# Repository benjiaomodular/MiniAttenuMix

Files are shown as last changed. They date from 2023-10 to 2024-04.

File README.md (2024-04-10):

# MiniAttenuMix

[][cc-by-sa]

A CV mixer with attenuverted inputs.

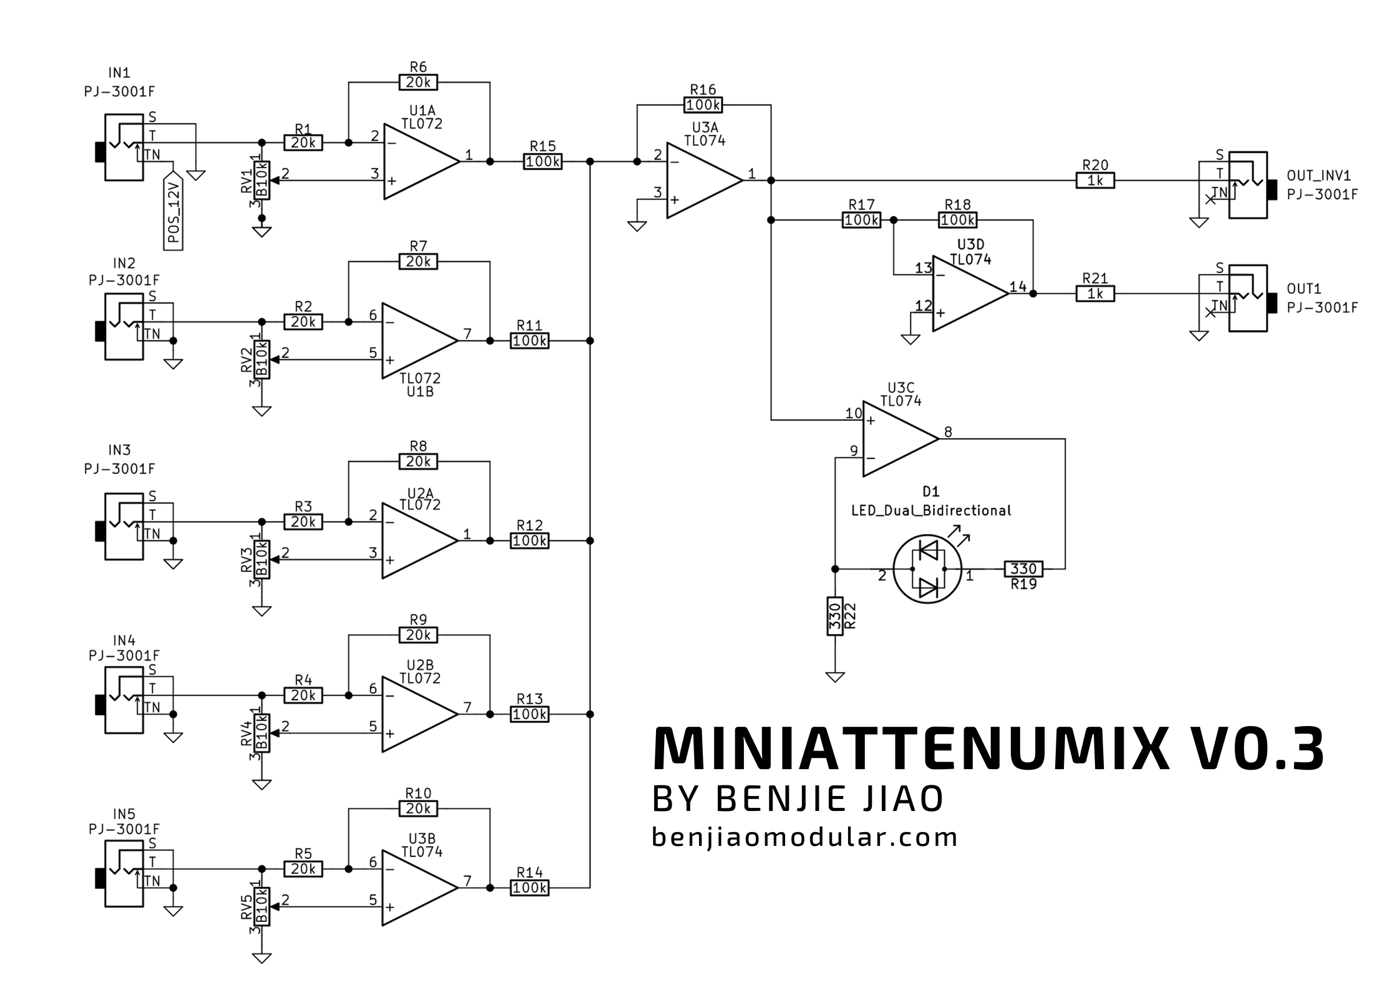
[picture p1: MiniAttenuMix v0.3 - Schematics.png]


# Dependencies
- Made with Kicad v6.
- Install my [KiCAD Libraries](https://github.com/benjiaomodular/KiCadLibraries).

# Changelog

## v0.3 LED Fix 2 (Unverified)
- Moved wiring of LED to the output of first mixing stage (Pin 1 of U3)
- Mistake on OpAmp setup for LED.

## v0.2 LED Fix (Does not work)
- Moved wiring of LED to the output of first mixing stage (Pin 1 of U3)
- Mistake on OpAmp setup for LED.

## v0.1 Initial Release (Does not work)
- LED doesn't function properly

# License

This work is licensed under a
[Creative Commons Attribution-ShareAlike 4.0 International License][cc-by-sa].

[][cc-by-sa]

[cc-by-sa]: http://creativecommons.org/licenses/by-sa/4.0/
[cc-by-sa-image]: https://licensebuttons.net/l/by-sa/4.0/88x31.png
[cc-by-sa-shield]: https://img.shields.io/badge/License-CC%20BY--SA%204.0-lightgrey.svg

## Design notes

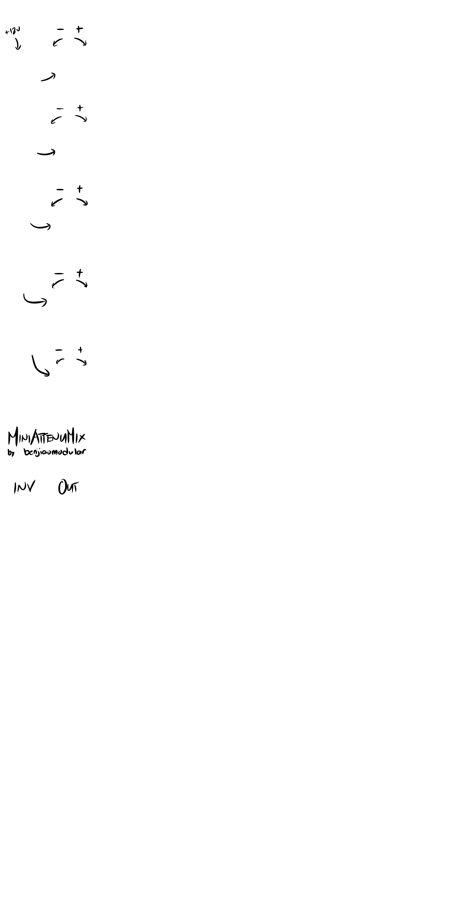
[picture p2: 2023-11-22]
MiniAttenuMix/MiniAttenuMix v0.3/MiniAttenumix - Panel/.svg2shenzhen-cache/images/F.SilkS_g1418.png

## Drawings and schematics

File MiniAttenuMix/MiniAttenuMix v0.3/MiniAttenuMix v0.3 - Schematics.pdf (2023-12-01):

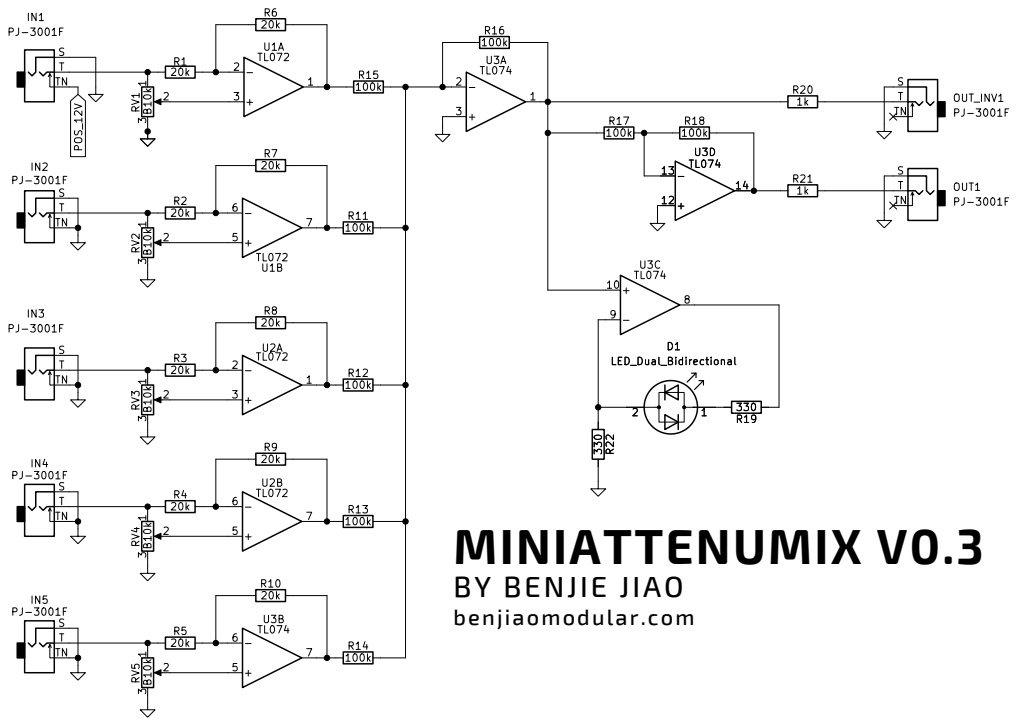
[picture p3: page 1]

MINIATTENUMIX V0.3
BY BENJIE JIAO
benjiaomodular.com

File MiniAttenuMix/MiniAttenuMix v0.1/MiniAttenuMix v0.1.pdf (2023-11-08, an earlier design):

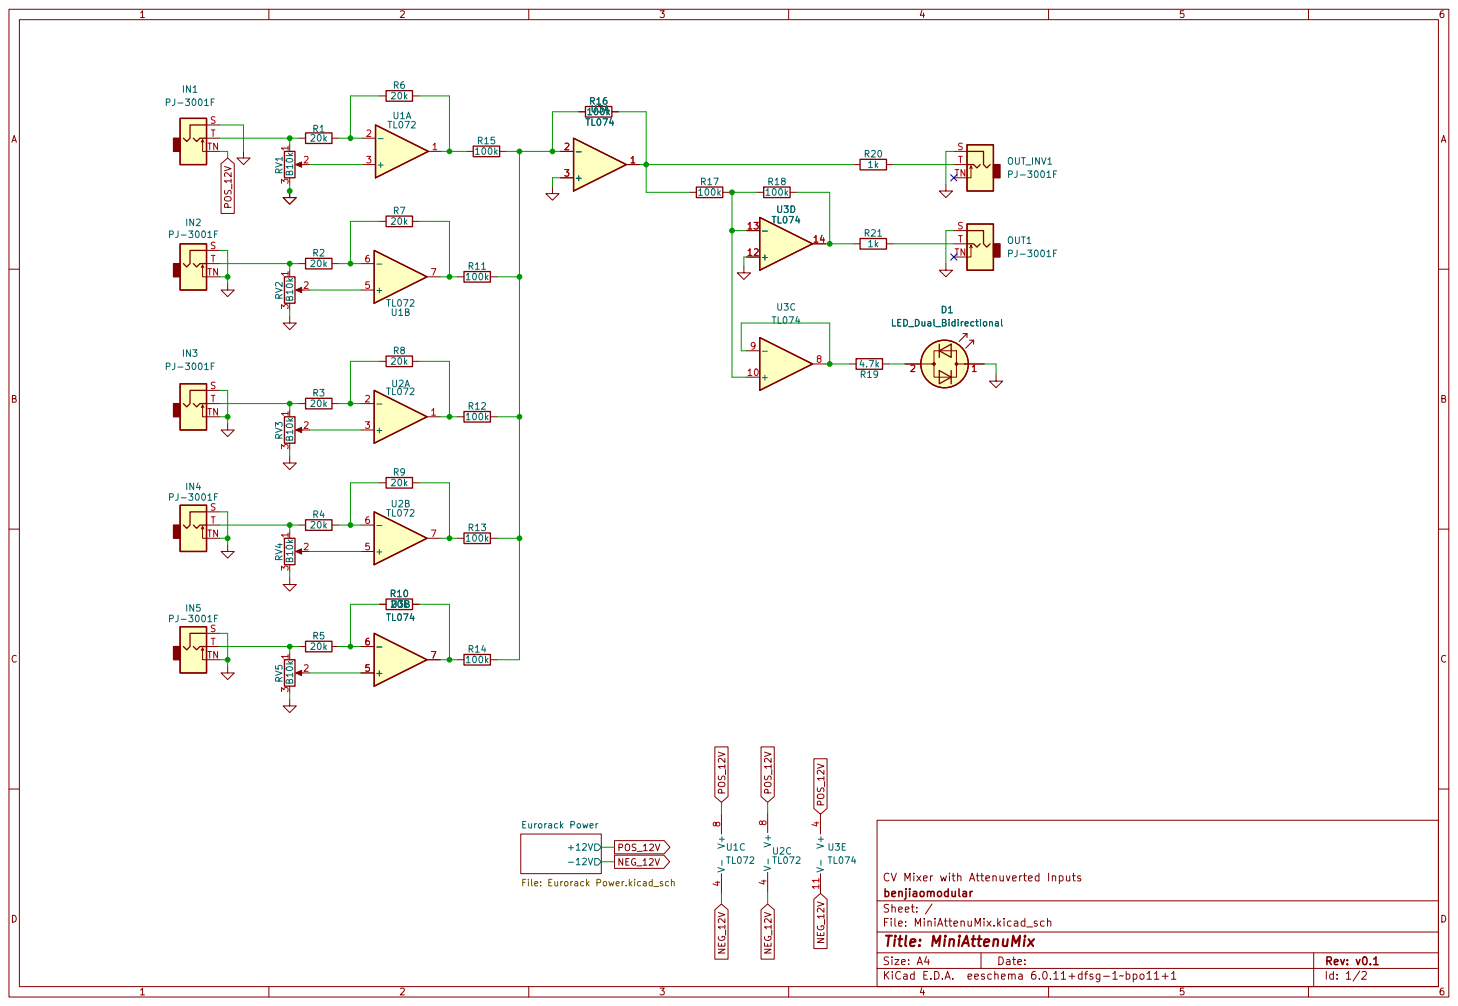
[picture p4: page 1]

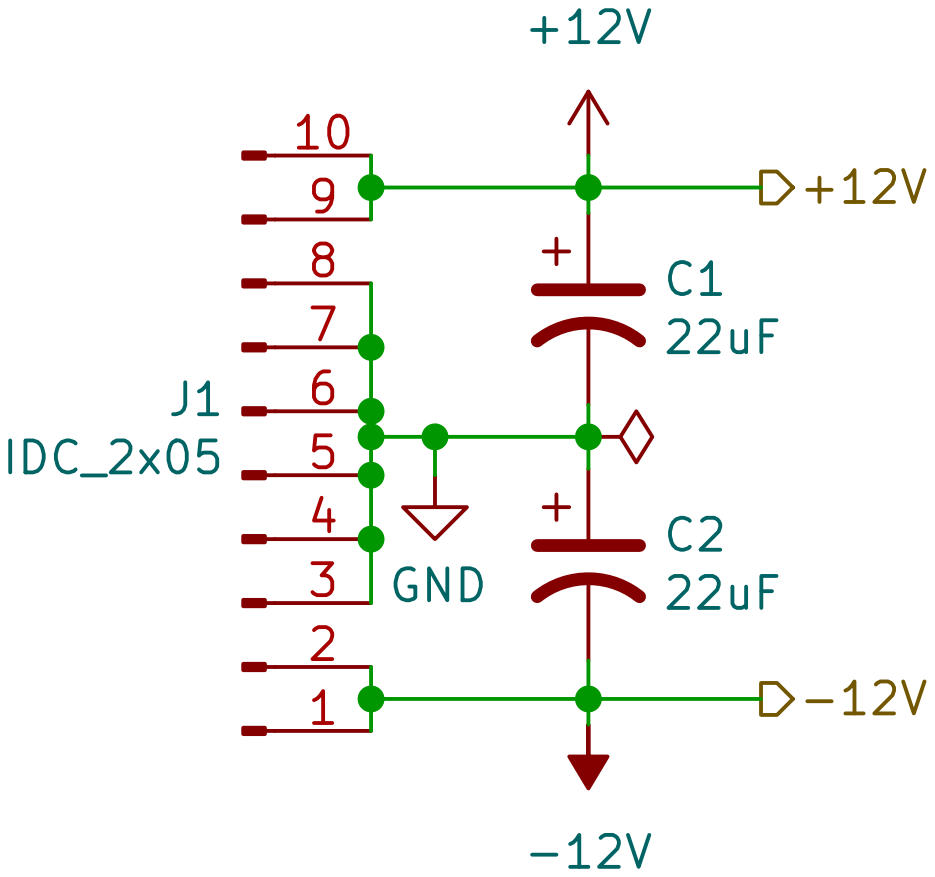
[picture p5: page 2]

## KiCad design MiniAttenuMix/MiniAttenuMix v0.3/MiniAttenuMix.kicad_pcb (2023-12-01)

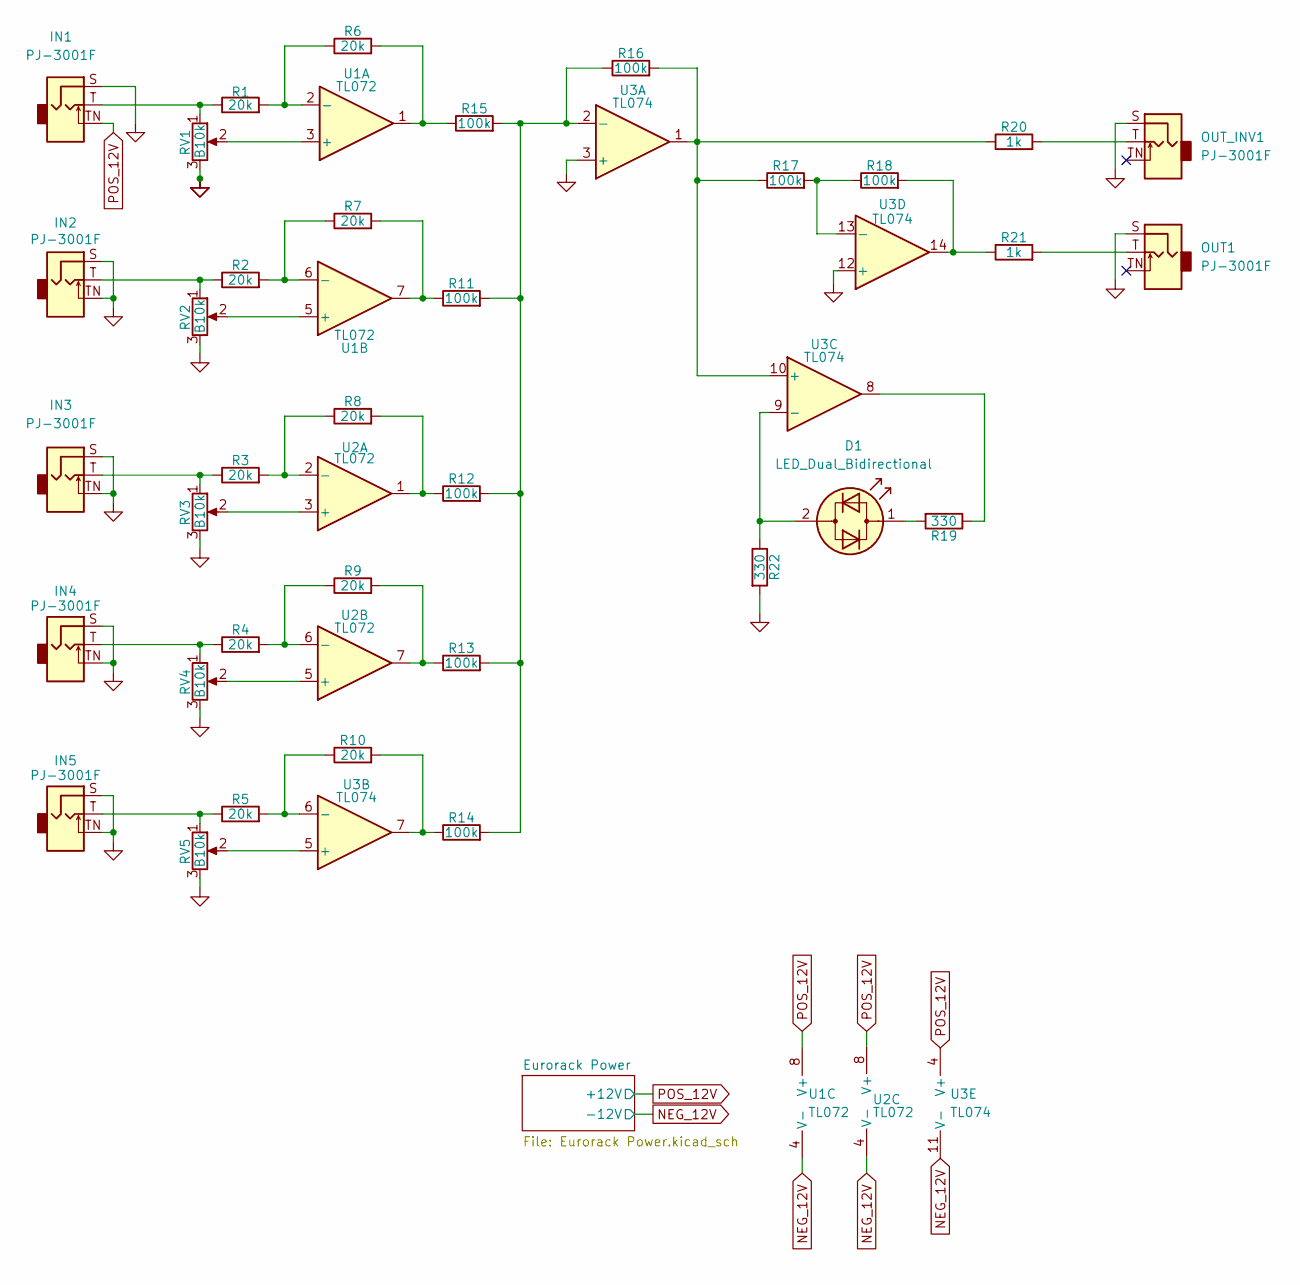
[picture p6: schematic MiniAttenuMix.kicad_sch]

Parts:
D1: LED_Dual_Bidirectional; LED_D3.0mm; Manufacturers Part Numb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 3ARG4HWC
IN1, IN2, IN3, IN4, IN5: PJ-3001F; AudioJack_3.5mm; Manufacturers Part Numb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 PJ-3001F
OUT1: PJ-3001F; AudioJack_3.5mm; Manufacturers Part Numb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 PJ-3001F
OUT_INV1: PJ-3001F; AudioJack_3.5mm; Manufacturers Part Numb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 PJ-3001F
R1, R2, R3, R4, R5, R6, R7, R8, R9, R10: 20k; R_0603_1608Metric_Pad0.98x0.95mm_HandSolder; Manufacturers Part Numb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 RC0603FR-0720KL
R11, R12, R13, R14, R15, R16, R17, R18: 100k; R_0603_1608Metric_Pad0.98x0.95mm_HandSolder; Manufacturers Part Numb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 RC0603FR-07100KL
R19, R22: 330; R_0603_1608Metric_Pad0.98x0.95mm_HandSolder; Manufacturers Part Numb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 CRG0603F330R
R20, R21: 1k; R_0603_1608Metric_Pad0.98x0.95mm_HandSolder; Manufacturers Part Numb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 RC0603FR-071KL
RV1, RV2, RV3, RV4, RV5: B10k; Potentiometer_RV09; Manufacturers Part Numb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 RD901F-40-15R1-B100K
U1, U2: TL072; SOIC-8_3.9x4.9mm_P1.27mm; Manufacturers Part Numb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 TL072CDT
U3: TL074; SOIC-14_3.9x8.7mm_P1.27mm; Manufacturers Part Numb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 TL074ACDT

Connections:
GND: IN1.S, IN2.S, IN2.TN, IN3.S, IN3.TN, IN4.S, IN4.TN, IN5.S, IN5.TN, OUT1.S, OUT_INV1.S, R22.2, RV1.3, RV2.3, RV3.3, RV4.3, RV5.3, U3.3 (+), U3.12 (+); also elsewhere on the board
NEG_12V: U1.4 (V-), U2.4 (V-), U3.11 (V-); also elsewhere on the board
unnamed: D1.1 (KA), R19.2
unnamed: D1.2 (AK), R22.1, U3.9 (-)
unnamed: IN1.T, R1.1, RV1.1
unnamed: IN2.T, R2.1, RV2.1
unnamed: IN3.T, R3.1, RV3.1
unnamed: IN4.T, R4.1, RV4.1
unnamed: IN5.T, R5.1, RV5.1
unnamed: OUT1.T, R21.2
unnamed: OUT_INV1.T, R20.2
unnamed: R1.2, R6.1, U1.2 (-)
unnamed: R2.2, R7.1, U1.6 (-)
unnamed: R3.2, R8.1, U2.2 (-)
unnamed: R4.2, R9.1, U2.6 (-)
unnamed: R5.2, R10.1, U3.6 (-)
unnamed: R10.2, R14.1, U3.7
unnamed: R7.2, R11.1, U1.7
unnamed: R11.2, R12.2, R13.2, R14.2, R15.2, R16.1, U3.2 (-)
unnamed: R8.2, R12.1, U2.1
unnamed: R9.2, R13.1, U2.7
unnamed: R6.2, R15.1, U1.1
unnamed: R17.2, R18.1, U3.13 (-)
unnamed: R18.2, R21.1, U3.14
unnamed: R19.1, U3.8
unnamed: RV1.2, U1.3 (+)
unnamed: RV2.2, U1.5 (+)
unnamed: RV3.2, U2.3 (+)
unnamed: RV4.2, U2.5 (+)
unnamed: RV5.2, U3.5 (+)
unnamed: R16.2, R17.1, R20.1, U3.1, U3.10 (+)
POS_12V: IN1.TN, U1.8 (V+), U2.8 (V+), U3.4 (V+); also elsewhere on the board

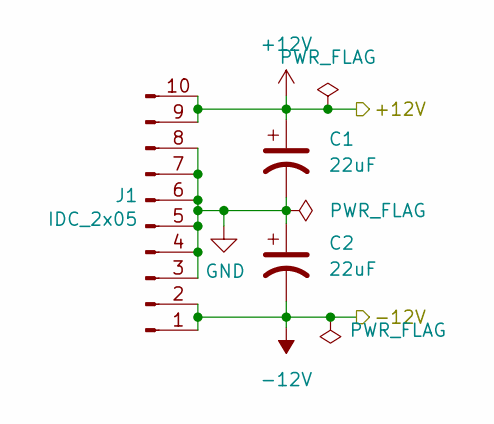
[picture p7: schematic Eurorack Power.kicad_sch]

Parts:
C1, C2: 22uF; C_0805_2012Metric_Pad1.18x1.45mm_HandSolder; Manufacturers Part Numb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 GRM21BR61E226ME44L
J1: IDC_2x05; IDC-Header_2x05_P2.54mm_Vertical; Manufacturers Part Numb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 X9555WV-2X05-6TV01; LCSC Part # C706914

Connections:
GND: C1.2, C2.1, J1.3, J1.4, J1.5, J1.6, J1.7, J1.8; also elsewhere on the board
NEG_12V: C2.2, J1.1, J1.2; also elsewhere on the board
POS_12V: C1.1, J1.9, J1.10; also elsewhere on the board

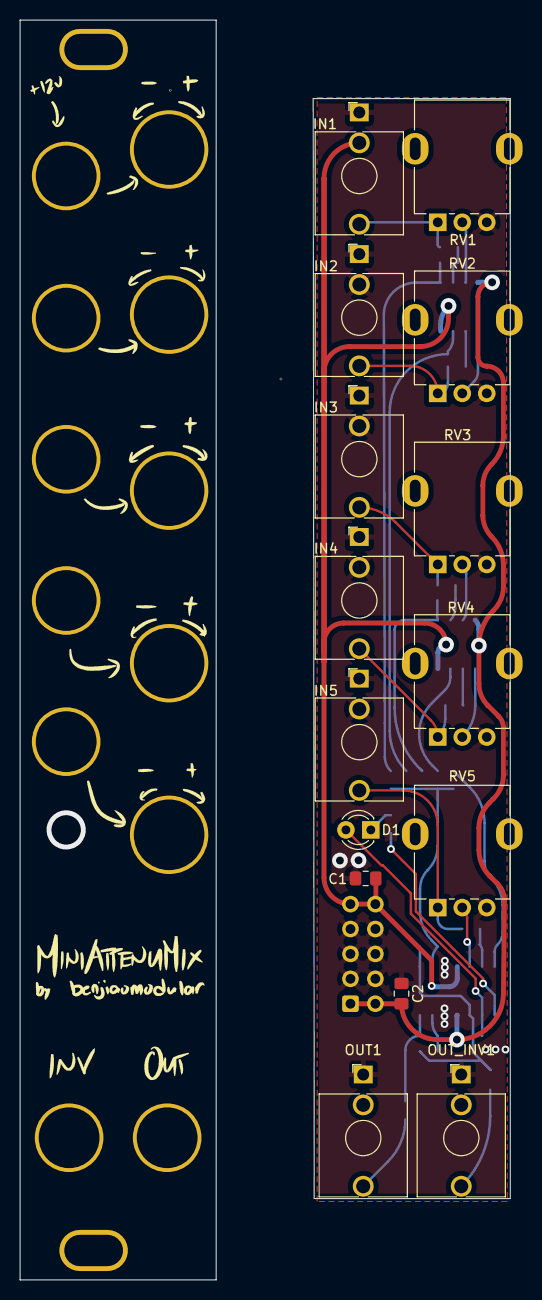
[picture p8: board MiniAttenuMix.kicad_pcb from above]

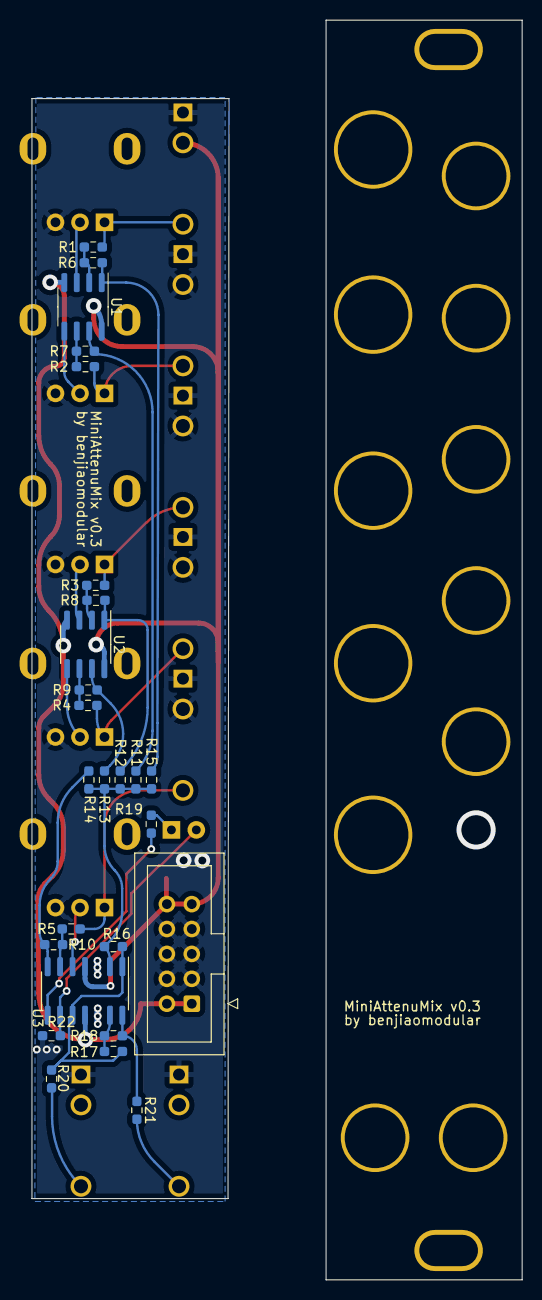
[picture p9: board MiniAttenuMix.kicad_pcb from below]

Board: 2 copper layers, 50.0 x 128.5 mm, 41 parts (26 on the bottom side), 32 nets.

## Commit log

2023-09-24 hello git
    [Eurorack Power.kicad_sch, MiniAttenuMix.kicad_pcb, MiniAttenuMix.kicad_sch]
2023-10-10 Added pcb for v0.1
    [Eurorack Power.kicad_sch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]
2023-11-08 Started v0.2
    [Eurorack Power.kicad_sch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]
2023-11-22 Added v0.2 gerbers
    [Eurorack Power.kicad_sch, MiniAttenuMix - Front Panel.kicad_pcb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]
2023-12-01 Added v0.3
    [Eurorack Power.kicad_sch, MiniAttenuMix - Front Panel.kicad_pcb, MiniAttenuMix.kicad_pcb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]
2023-12-01 Updated schematics on docs
2023-12-01 updated v0.3 fabrication files
    [MiniAttenuMix - Front-B_Cu.gbr, MiniAttenuMix - Front-B_Mask.gbr, MiniAttenuMix - Front-B_Paste.gbr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]

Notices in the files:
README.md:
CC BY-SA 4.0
